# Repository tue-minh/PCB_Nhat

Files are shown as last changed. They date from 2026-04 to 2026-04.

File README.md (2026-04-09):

# 📘 PCB Review 

---

## 🖼️ PCB Images

### 🔵 Front View
<p align="center">
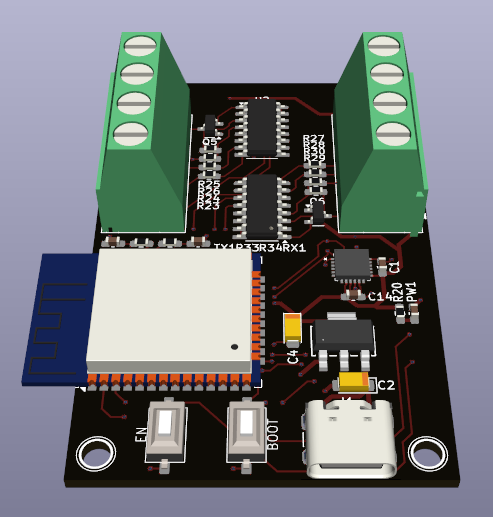
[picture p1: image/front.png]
Front PCB
  
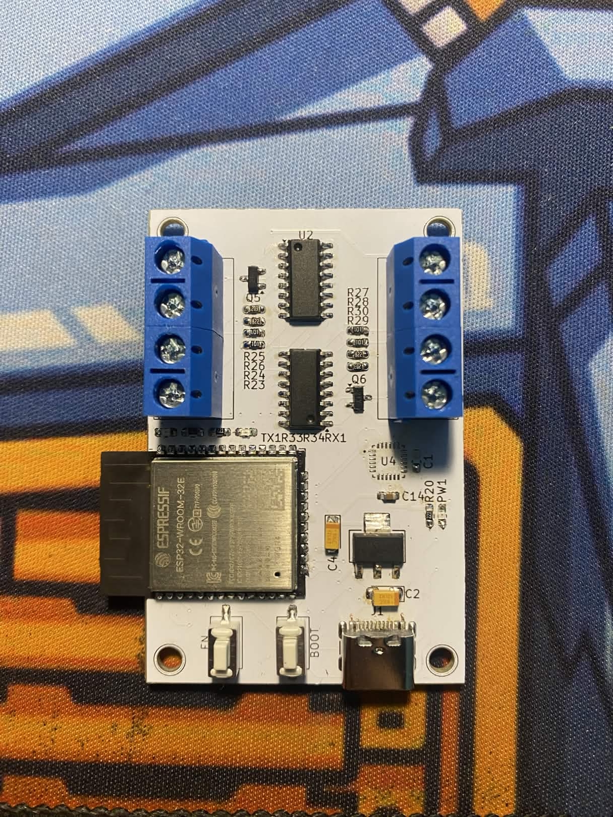
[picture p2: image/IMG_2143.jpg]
  
</p>

---

### 🔴 Back View
<p align="center">
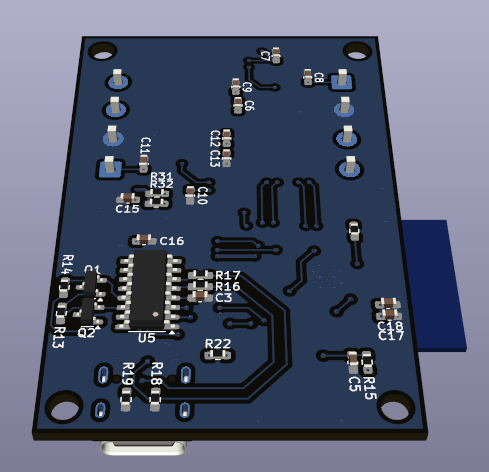
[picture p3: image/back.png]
Back PCB
  
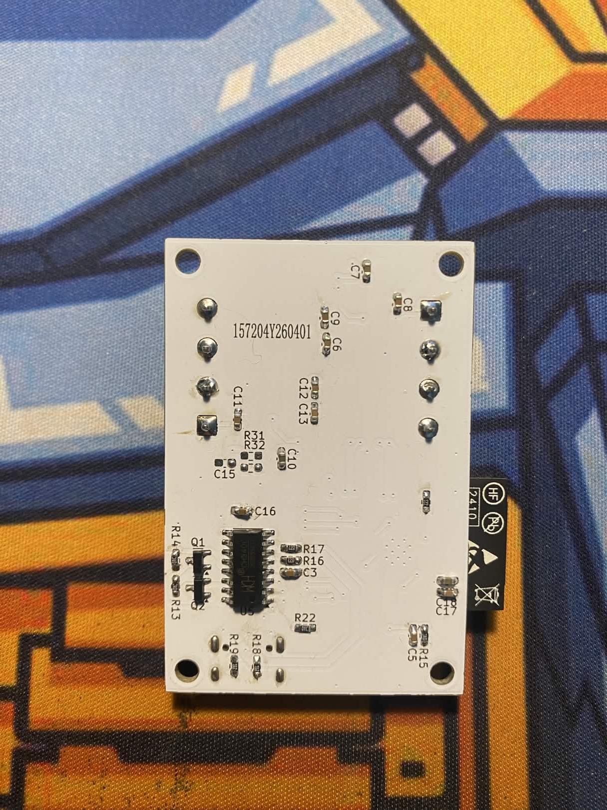
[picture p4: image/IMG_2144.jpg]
  

</p>

---

### 🟢 Routing View
<p align="center">
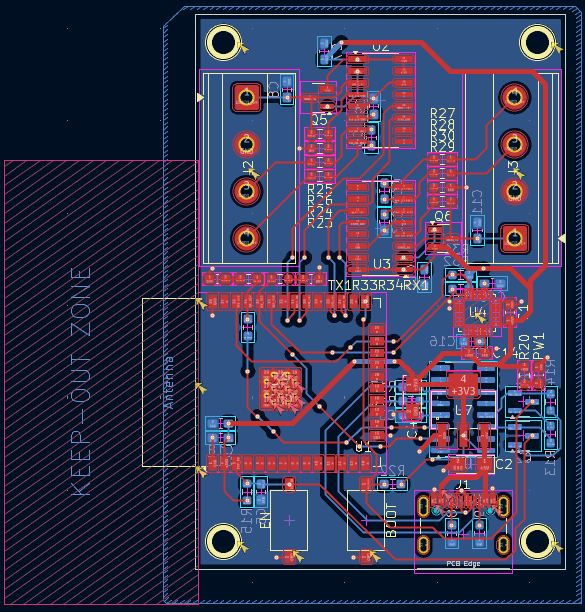
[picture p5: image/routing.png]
Routing PCB
  
</p>

---

## 📄 Schematic

📥 Nhấn vào link bên dưới để xem sơ đồ nguyên lý:

👉 [Open Schematic PDF](image/Schematic.pdf)

---

## 📝 Notes
- Kích thước mạch: 60 x 40 (mm)
- Khoảng cách lỗ: 54 x 34 (mm)
- Pinout: 

| ESP32  | HX711 | MPU6050 |
|---|---|---|
| GPIO19 | DOUT1 | |
| GPIO18 | SCK1  | |
| GPIO16 | DOUT2 | |
| GPIO17 | SCK2  | |
| GPIO21 | | SDA |
| GPIO22 | | SCL |

---

## ✅ BOM
- [ ] SOC - ESP WROOM 32 (x1)
- [ ] IC - HX711 IC (x2)
- [ ] IC - CH340C (x1)
- [ ] IC - MPU6050 (x1)
- [ ] LDO - AMS1117 3V3 (x1)
- [ ] Transistor - SS8050 NPN (x2)
- [ ] Transistor - SS8550 PNP (x2)
- [ ] Button SMD - 3x6x2.5 (mm) (x2)
- [ ] Connector - TypeC 16P USB2.0 (x1)
- [ ] Connector - Terminal block 5.08 mm - 4 Pin (x2)
- [ ] Capacitor Tantalum - 3216 (Check schematic)
- [ ] Capacitor SMD - 0603 (Check schematic)
- [ ] Resistor SMD - 0603 (Check schematic)

---

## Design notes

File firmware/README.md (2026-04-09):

> The **loadcell.h** library is hosted here:  
> ## [HELLO WORLD](https://github.com/tue-minh/Sensor_Loadcell)

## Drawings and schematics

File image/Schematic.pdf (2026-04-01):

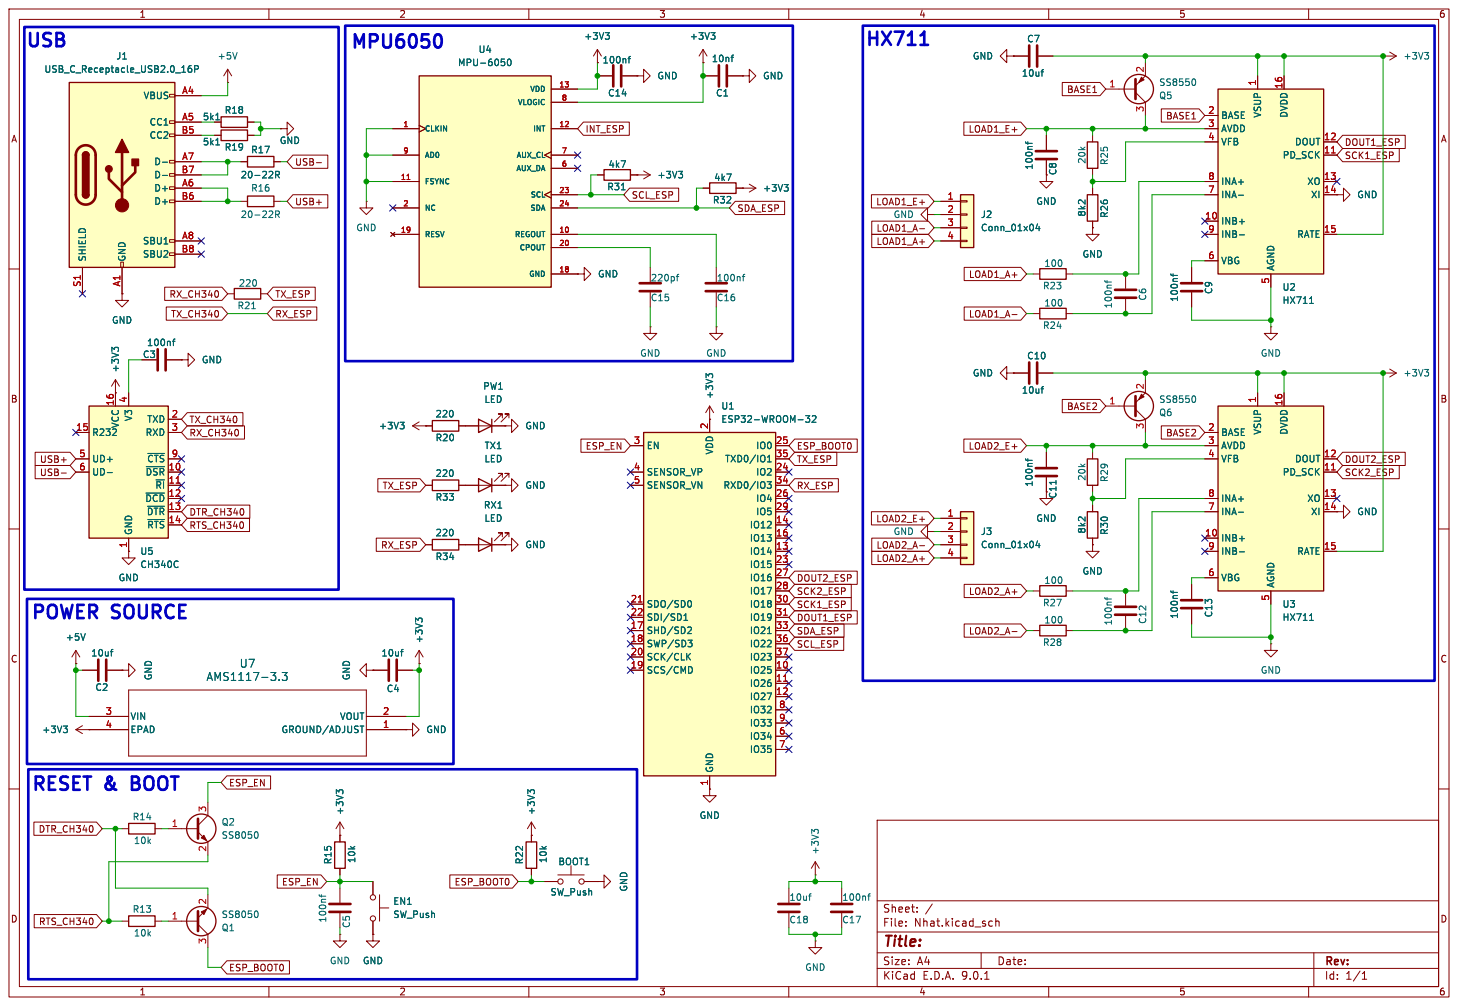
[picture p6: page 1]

5 DVDD 16 DOUT 12 PD_SCK 11 XO 13 XI 14 RATE 15 U2 HX711 C4

5 DVDD 16 DOUT 12 PD_SCK 11 XO 13 XI 14 RATE 15 GND

5 DVDD 16 DOUT 12 PD_SCK 11 XO 13 XI 14 RATE 15 GND 8k2 R30 GND GND

5 DVDD 16 DOUT 12 PD_SCK 11 XO 13 XI 14 RATE 15 U3 HX711 GND GND

1 TXD 2 RXD 3 ~{CTS}9 ~{DSR} 10 ~{RI} 11 ~{DCD} 12 ~{DTR} 13 ~{RTS} 14 U5 CH340C

1 TXD 2 RXD 3 ~{CTS}9 ~{DSR} 10 ~{RI} 11 ~{DCD} 12 ~{DTR} 13 ~{RTS} 14 GND

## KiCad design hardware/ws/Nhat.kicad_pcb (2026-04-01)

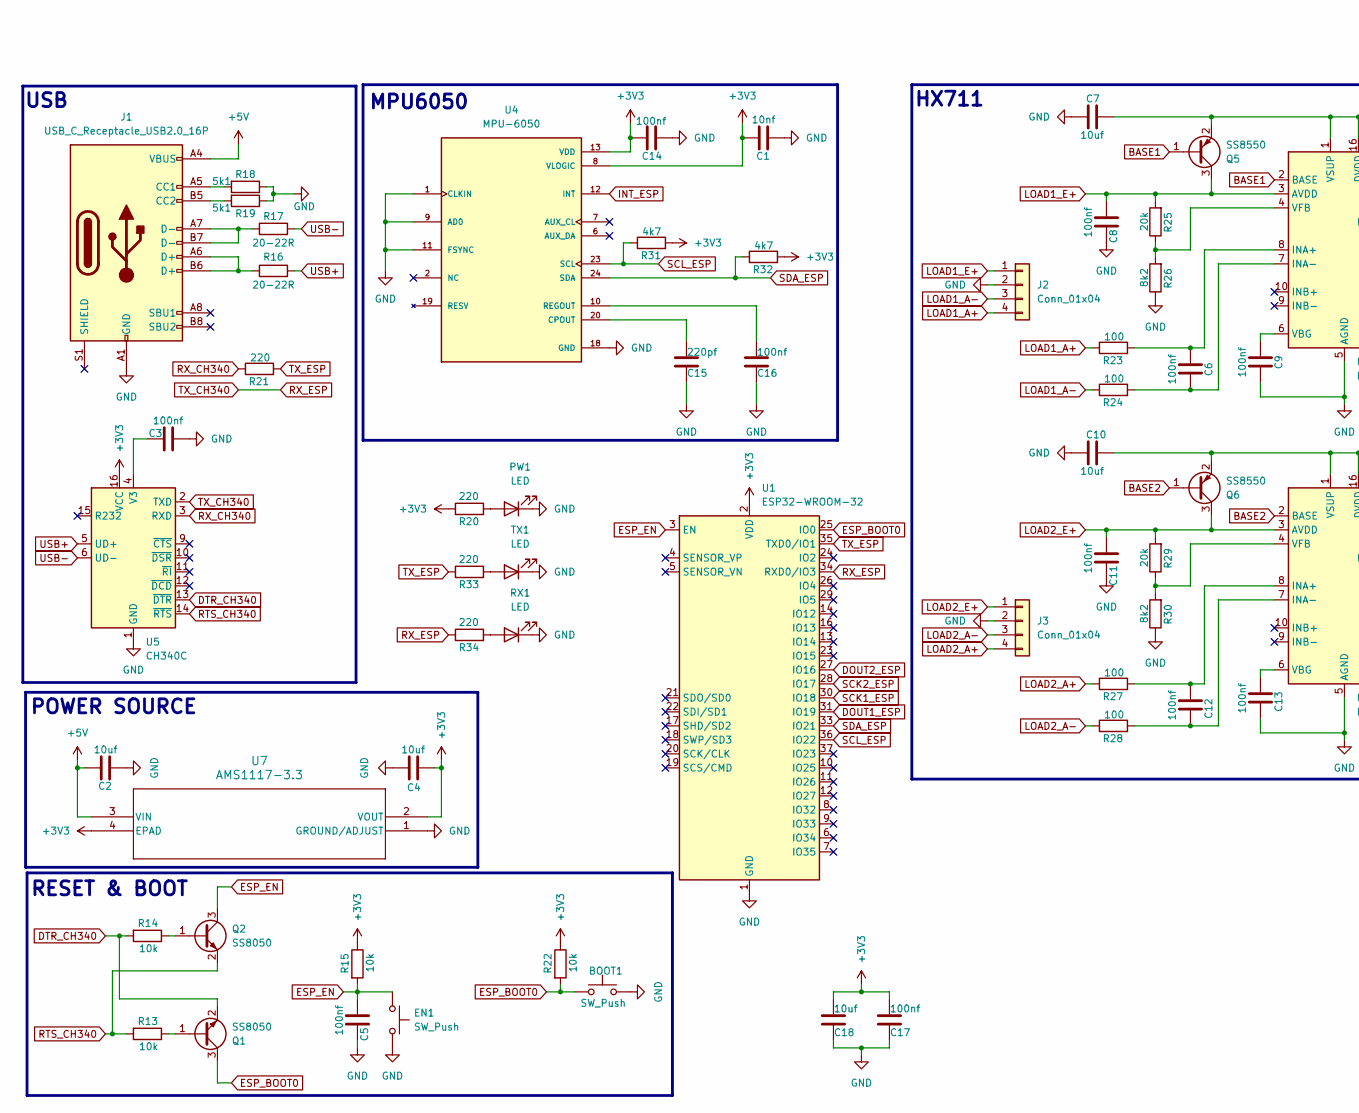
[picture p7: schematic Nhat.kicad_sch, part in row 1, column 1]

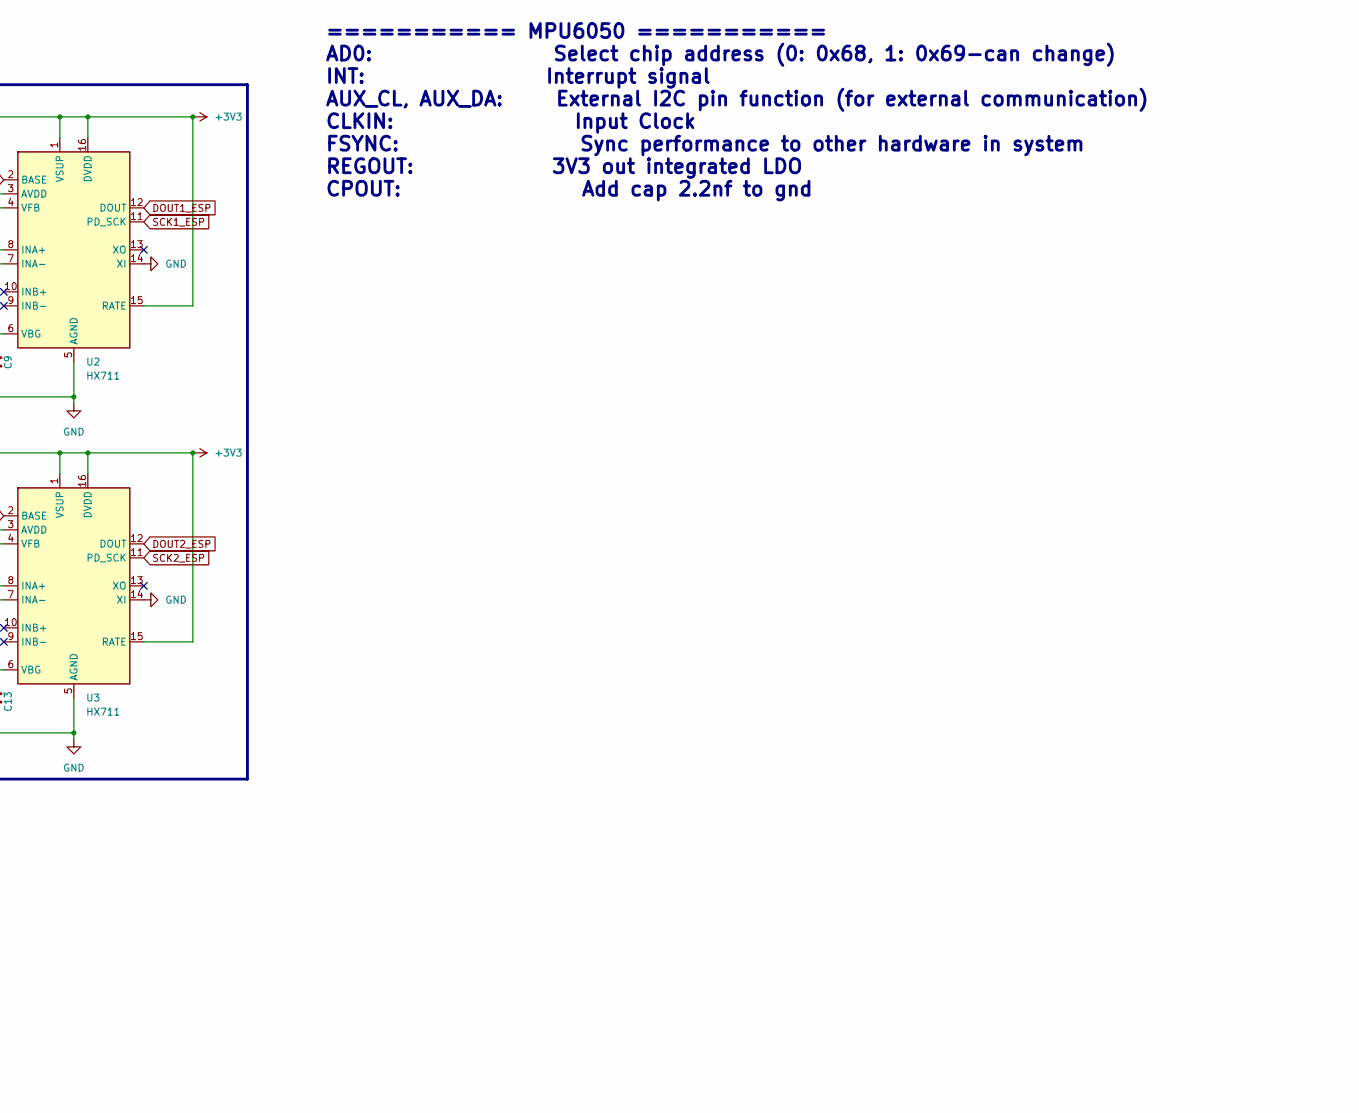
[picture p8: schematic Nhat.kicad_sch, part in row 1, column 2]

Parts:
BOOT1: SW_Push; tue_sw_smd_3x6x2.5mm
C1: 10nf; C_0603_1608Metric_Pad1.08x0.95mm_HandSolder
C2, C4: 10uf; CP_EIA-3216-12_Kemet-S_HandSolder
C3, C5, C6, C8, C9, C11, C12, C13, C14, C16, C17: 100nf; C_0603_1608Metric_Pad1.08x0.95mm_HandSolder
C7, C10, C18: 10uf; C_0603_1608Metric_Pad1.08x0.95mm_HandSolder
C15: 220pf; C_0603_1608Metric_Pad1.08x0.95mm_HandSolder
EN1: SW_Push; tue_sw_smd_3x6x2.5mm
J1: USB_C_Receptacle_USB2.0_16P; USB_C_Receptacle_GCT_USB4105-xx-A_16P_TopMnt_Horizontal
J2, J3: Conn_01x04; TerminalBlock_Phoenix_MKDS-1,5-4-5.08_1x04_P5.08mm_Horizont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
PW1: LED; C_0603_1608Metric_Pad1.08x0.95mm_HandSolder
Q1, Q2: SS8050; SOT-23
Q5, Q6: SS8550; SOT-23
R13, R14, R15, R22: 10k; R_0603_1608Metric_Pad0.98x0.95mm_HandSolder
R16, R17: 20-22R; R_0603_1608Metric_Pad0.98x0.95mm_HandSolder
R18, R19: 5k1; R_0603_1608Metric_Pad0.98x0.95mm_HandSolder
R20, R21, R33, R34: 220; R_0603_1608Metric_Pad0.98x0.95mm_HandSolder
R23, R24, R27, R28: 100; R_0603_1608Metric_Pad0.98x0.95mm_HandSolder
R25, R29: 20k; R_0603_1608Metric_Pad0.98x0.95mm_HandSolder
R26, R30: 8k2; R_0603_1608Metric_Pad0.98x0.95mm_HandSolder
R31, R32: 4k7; R_0603_1608Metric_Pad0.98x0.95mm_HandSolder
RX1: LED; C_0603_1608Metric_Pad1.08x0.95mm_HandSolder
TX1: LED; C_0603_1608Metric_Pad1.08x0.95mm_HandSolder
U1: ESP32-WROOM-32
U2, U3: HX711; SOP-16_3.9x9.9mm_P1.27mm
U4: MPU-6050; QFN50P400X400X95-24N; PARTREV 3.4
U5: CH340C; SOIC-16_3.9x9.9mm_P1.27mm
U7: AMS1117-3.3; SOT_AMS_ADS

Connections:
+3V3: C1.1, C4.1, C7.1, C10.1, C14.1, C17.1, C18.1, Q5.2 (E), Q6.2 (E), R15.1, R20.1, R22.1, R31.2, R32.2, U1.2 (VDD), U2.1 (VSUP), U2.15 (RATE), U2.16 (DVDD), U3.1 (VSUP), U3.15 (RATE), U3.16 (DVDD), U4.8 (VLOGIC), U4.13 (VDD), U5.16 (VCC), U7.2 (VOUT), U7.4 (EPAD)
+5V: C2.1, J1.A4 (VBUS), J1.A9 (VBUS), J1.B4 (VBUS), J1.B9 (VBUS), U7.3 (VIN)
BASE1: Q5.1 (B), U2.2 (BASE)
BASE2: Q6.1 (B), U3.2 (BASE)
DOUT1_ESP: U1.31 (IO19), U2.12 (DOUT)
DOUT2_ESP: U1.27 (IO16), U3.12 (DOUT)
DTR_CH340: Q1.2 (E), R14.2, U5.13 (~DTR)
ESP_BOOT0: BOOT1.1, Q1.3 (C), R22.2, U1.25 (IO0)
ESP_EN: C5.2, EN1.1, Q2.3 (C), R15.2, U1.3 (EN)
GND: BOOT1.2, C1.2, C2.2, C3.2, C4.2, C5.1, C7.2, C8.1, C9.1, C10.2, C11.1, C13.1, C14.2, C15.2, C16.2, C17.2, C18.2, EN1.2, J1.A1 (GND), J1.A12 (GND), J1.B1 (GND), J1.B12 (GND), J2.2, J3.2, PW1.1 (K), R18.1, R19.1, R26.1, R30.1, RX1.1 (K), TX1.1 (K), U1.1 (GND), U1.15 (GND), U1.38 (GND), U1.39 (GND), U2.5 (AGND), U2.14 (XI), U3.5 (AGND), U3.14 (XI), U4.1 (CLKIN), U4.9 (AD0), U4.11 (FSYNC), U4.18 (GND), U5.1 (GND), U7.1 (GROUND/ADJUST)
INT_ESP: U4.12 (INT)
LOAD1_A+: J2.4, R23.1
LOAD1_A-: J2.3, R24.1
LOAD1_E+: C8.2, J2.1, Q5.3 (C), R25.2, U2.3 (AVDD)
LOAD2_A+: J3.4, R27.1
LOAD2_A-: J3.3, R28.1
LOAD2_E+: C11.2, J3.1, Q6.3 (C), R29.2, U3.3 (AVDD)
unnamed: J1.A5 (CC1), R18.2
unnamed: J1.B5 (CC2), R19.2
unnamed: J1.A6 (D+), J1.B6 (D+), R16.1
unnamed: J1.A7 (D-), J1.B7 (D-), R17.1
unnamed: PW1.2 (A), R20.2
unnamed: Q1.1 (B), R13.1
unnamed: Q2.1 (B), R14.1
unnamed: R34.2, RX1.2 (A)
unnamed: R33.2, TX1.2 (A)
unnamed: C6.2, R23.2, U2.8 (INA+)
unnamed: C6.1, R24.2, U2.7 (INA-)
unnamed: C9.2, U2.6 (VBG)
unnamed: R25.1, R26.2, U2.4 (VFB)
unnamed: C12.2, R27.2, U3.8 (INA+)
unnamed: C12.1, R28.2, U3.7 (INA-)
unnamed: C13.2, U3.6 (VBG)
unnamed: R29.1, R30.2, U3.4 (VFB)
unnamed: C15.1, U4.20 (CPOUT)
unnamed: C16.1, U4.10 (REGOUT)
unnamed: C3.1, U5.4 (V3)
RTS_CH340: Q2.2 (E), R13.2, U5.14 (~RTS)
RX_CH340: R21.1, U5.3 (RXD)
RX_ESP: R34.1, U1.34 (RXD0/IO3), U5.2 (TXD)
SCK1_ESP: U1.30 (IO18), U2.11 (PD_SCK)
SCK2_ESP: U1.28 (IO17), U3.11 (PD_SCK)
SCL_ESP: R31.1, U1.36 (IO22), U4.23 (SCL)
SDA_ESP: R32.1, U1.33 (IO21), U4.24 (SDA)
TX_ESP: R21.2, R33.1, U1.35 (TXD0/IO1)
USB+: R16.2, U5.5 (UD+)
USB-: R17.2, U5.6 (UD-)

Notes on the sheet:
USB
HX711
=========== MPU6050 =========== AD0: Select chip address (0: 0x68, 1: 0x69-can change) INT: Interrupt signal AUX_CL, AUX_DA: External I2C pin function (for external communication) CLKIN: Input Clock FSYNC: Sync performance to other hardware in system REGOUT: 3V3 out integrated LDO CPOUT: Add cap 2.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
RESET & BOOT
MPU6050
POWER SOURCE

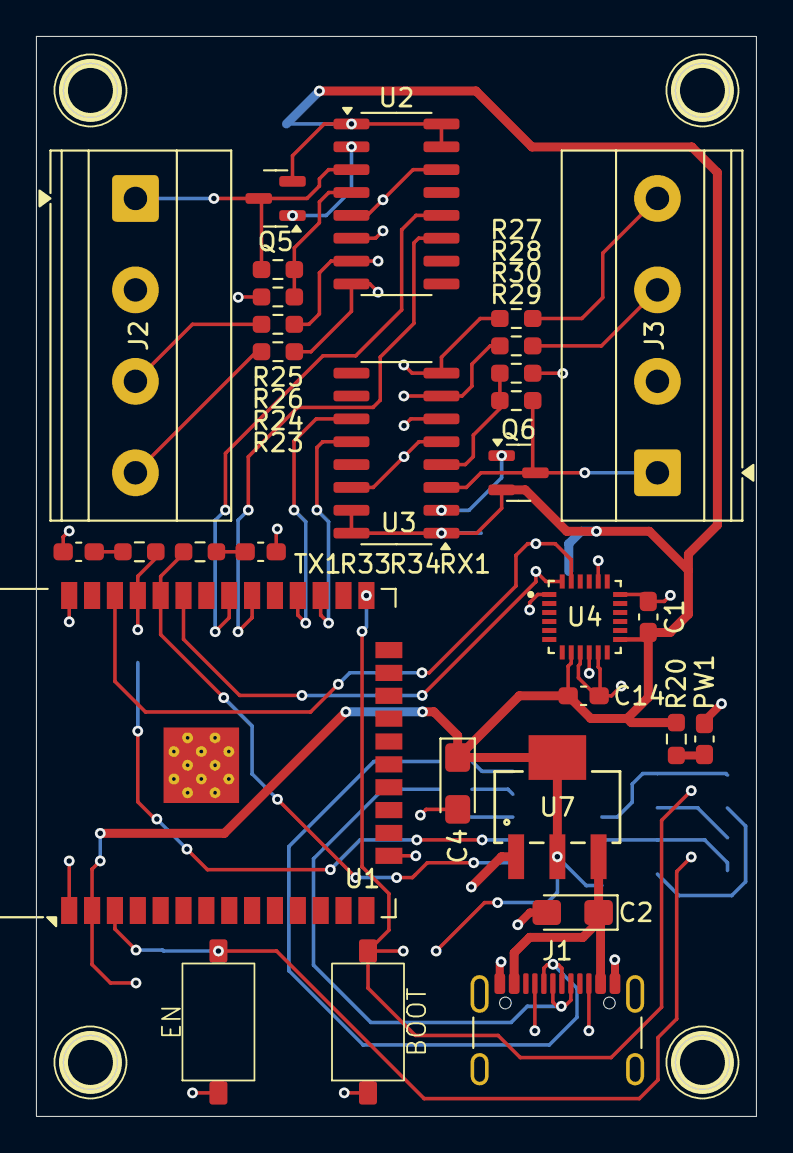
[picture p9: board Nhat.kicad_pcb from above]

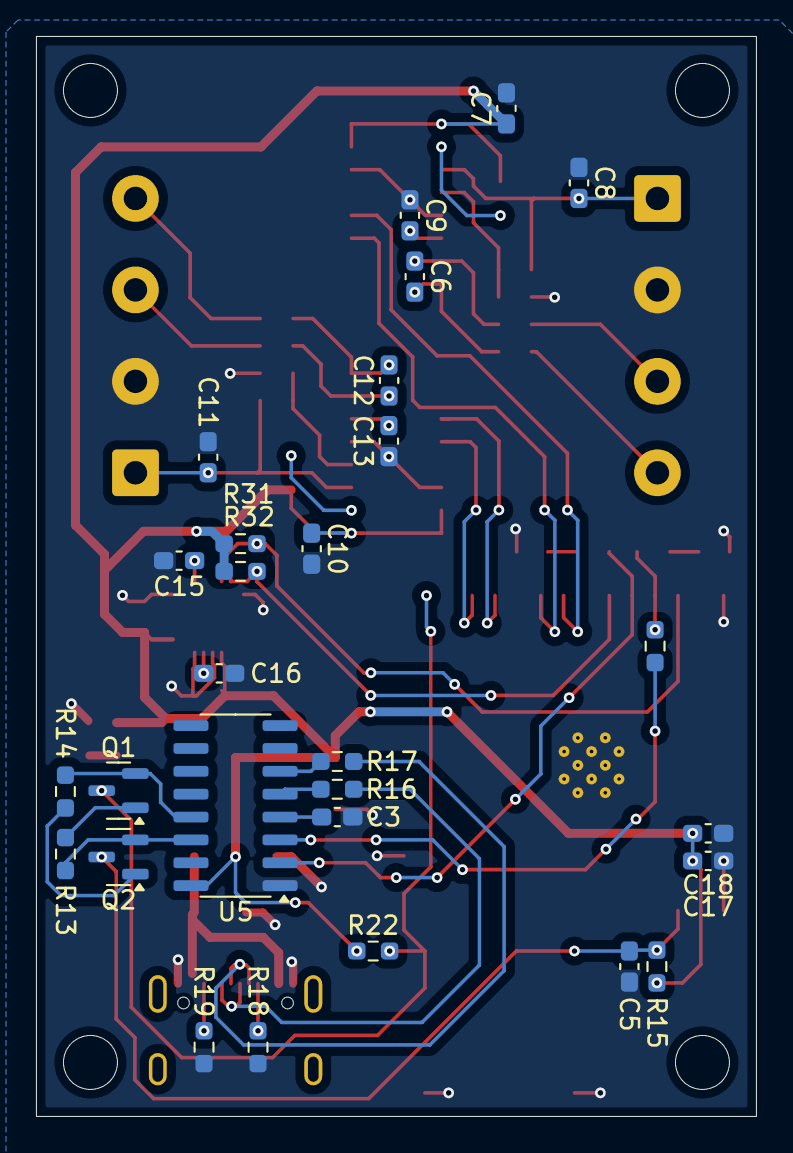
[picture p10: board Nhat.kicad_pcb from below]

Board: 2 copper layers, 40.0 x 60.0 mm, 58 parts (28 on the bottom side), 46 nets.

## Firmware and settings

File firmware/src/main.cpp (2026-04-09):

#include <Arduino.h>
// #include <HardwareSerial.h>
#include <loadcell.h>
// #include <KTransFunc.h>

#define SCK1 18
#define SCK2 17
#define DT1 19
#define DT2 16
#define SCALE1 948
#define SCALE2 948

double sensor_value1 = 0;
double sensor_value2 = 0;

Loadcell loadcell1 = Loadcell(SCK1, DT1, SCALE1);
Loadcell loadcell2 = Loadcell(SCK2, DT2, SCALE2);

void setup()
{
  Serial.begin(115200);
  loadcell1.init();
  loadcell2.init();
  loadcell1.reset_zero_offset();
  loadcell2.reset_zero_offset();
}

void loop()
{
  sensor_value1 = abs(loadcell1.read_value());
  sensor_value2 = abs(loadcell2.read_value());
  Serial.print("Load1: ");Serial.print(sensor_value1);
  Serial.print("\t");
  Serial.print("Load2: ");Serial.println(sensor_value2);
  // delay(20); // optional
}

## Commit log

2026-03-31 update schematic, routing
    [Nhat.kicad_pcb, Nhat.kicad_sch]
2026-03-31 relocate workspace, update image
    [Nhat.kicad_pcb, Nhat.kicad_sch]
2026-04-01 add Led
    [Nhat.kicad_pcb, Nhat.kicad_sch]
2026-04-01 add gerber file
    [Nhat-B_Cu.gbr, Nhat-B_Mask.gbr, Nhat-B_Paste.gbr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]
2026-04-09 update markdown file, relocate workspace
    [Nhat-B_Cu.gbr, Nhat-B_Mask.gbr, Nhat-B_Paste.gbr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]
